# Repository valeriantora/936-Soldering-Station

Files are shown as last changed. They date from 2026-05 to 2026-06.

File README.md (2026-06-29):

# 936-Soldering-Station

The **936 Soldering Station** is an open source hardware module designed for DIY 936 style soldering station builds and controller replacements. It features a transient protected, multi stage power architecture and integrated precision calibration points for high thermal accuracy and hardware longevity.

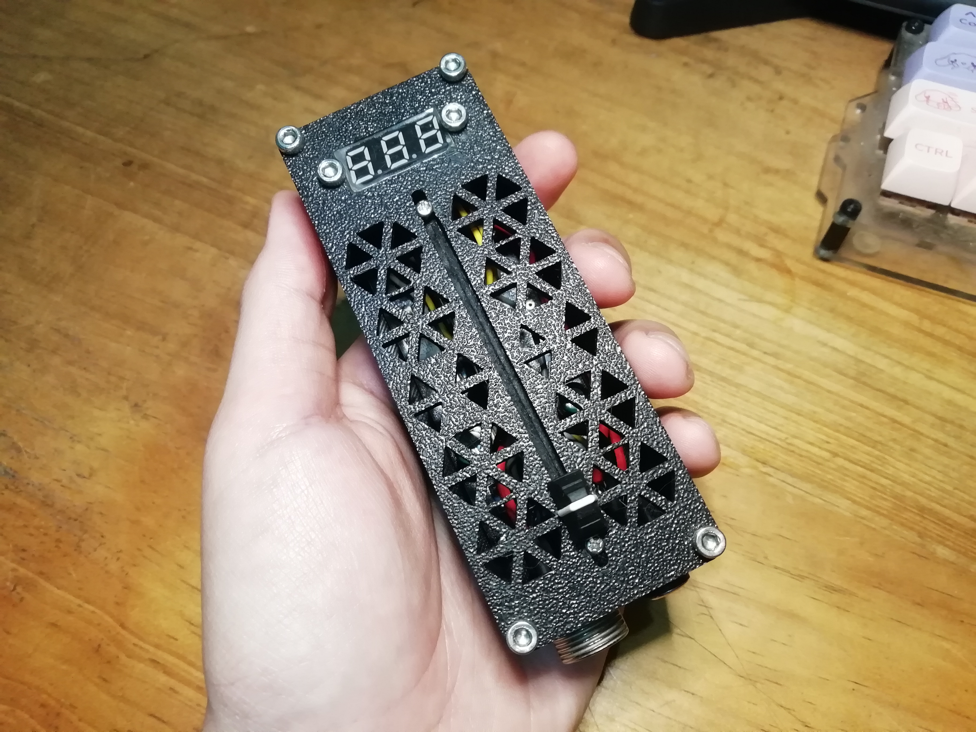
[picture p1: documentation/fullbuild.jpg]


## Key Features

* **Pure Analog Control:** Unlike many modern designs, this station uses no microcontrollers. By utilizing the widely available **[LM358](https://www.lcsc.com/datasheet/C5423.pdf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) op-amp**, the project remains easy to build, troubleshoot, and repair without the need for firmware flashing or specialized programming tools.
* **Schmitt Trigger Switching:** Utilizes to ensure the MOSFET operates strictly in a "snap-action" mode.
* **Multi-Stage Power Protection:** Implements an [LM2596S ](https://www.lcsc.com/datasheet/C347423.pdf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) buck converter to safely step down the main 24V input. This intermediate voltage then feeds the [78L12](https://www.lcsc.com/datasheet/C5337208.pdf) and [78L05](https://www.lcsc.com/datasheet/C347258.pdf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) linear regulators in parallel, preventing them from blowing out due to 24V hot-plug inductive spikes or thermal overload.
* **Temperature Monitoring:** Using a 3 wire digital voltmeter to provide real time temperature readout via calibrated analog scaling.
* **Dual Test-Point Calibration:** Equipped with dedicated onboard test points to safely measure and tune the intermediate buck regulation voltage and the amplified thermal feedback.
* **Linear Thermal Scaling:** Outbound thermocouple feedback is mapped linearly where 1V = 100°C, simplifying verification and calibration with any standard multimeter.

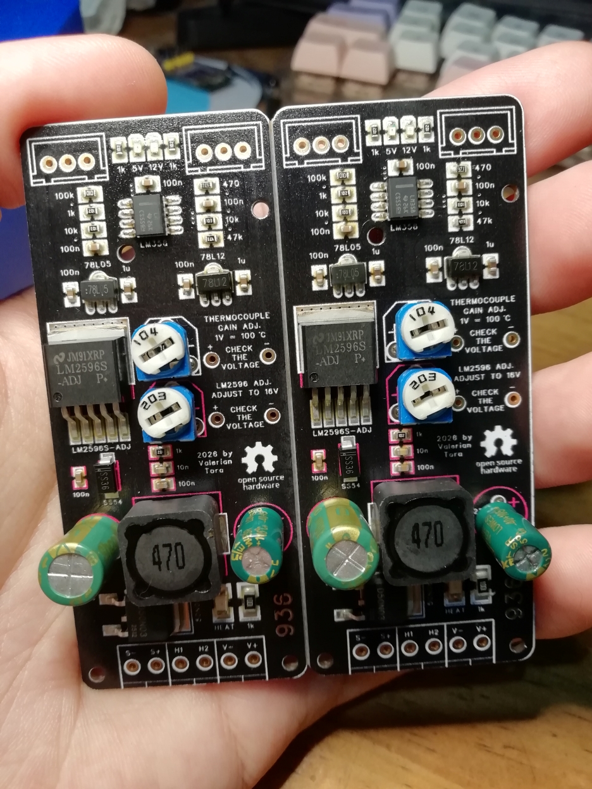
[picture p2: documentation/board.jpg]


## Technical Specifications

| Parameter | Specification |
| :--- | :--- |
| **Main Input Voltage** | 24V DC |
| **Control Architecture** | Analog Schmitt Trigger (LM358 Based) |
| **Power Supply Topology** | LM2596 Buck -> (7812 & 7805 in parallel) |
| **Analog Regulation** | 7812 (LM358 power) & 7805 (Potentiometer reference) |
| **Thermal Scaling** | 1V = 100°C at Test Point 1 (TP1) |
| **Switching Element** | TO-252 MOSFET Footprint (AOD444, 50N06, or equivalent) |

## Hardware & Calibration Layout

### 1. Power Calibration (TP2)
To protect the linear regulation stages from excessive thermal dissipation or overvoltage damage, the LM2596 output must be set precisely before reaching the 7812 and 7805 ICs.
* **Test Point:** TP2 (located directly side-by-side with the voltage calibration trimpot).
* **Procedure:** Measure voltage at TP2 against ground and adjust the potentiometer until the target pre-regulation voltage is met.

### 2. Thermal Feedback Verification (TP1)
The controller uses the LM358 op-amp (powered by the clean 12V rail) to amplify the microvolt signal from the iron's internal K-type thermocouple into a linear voltage output.
* **Test Point:** TP1 (monitors the output of the thermocouple operational amplifier).
* **Scaling Ratio:** Optimized at a 1V = 100°C ratio. For example, a reading of 3.5V directly represents a tip temperature of 350°C.

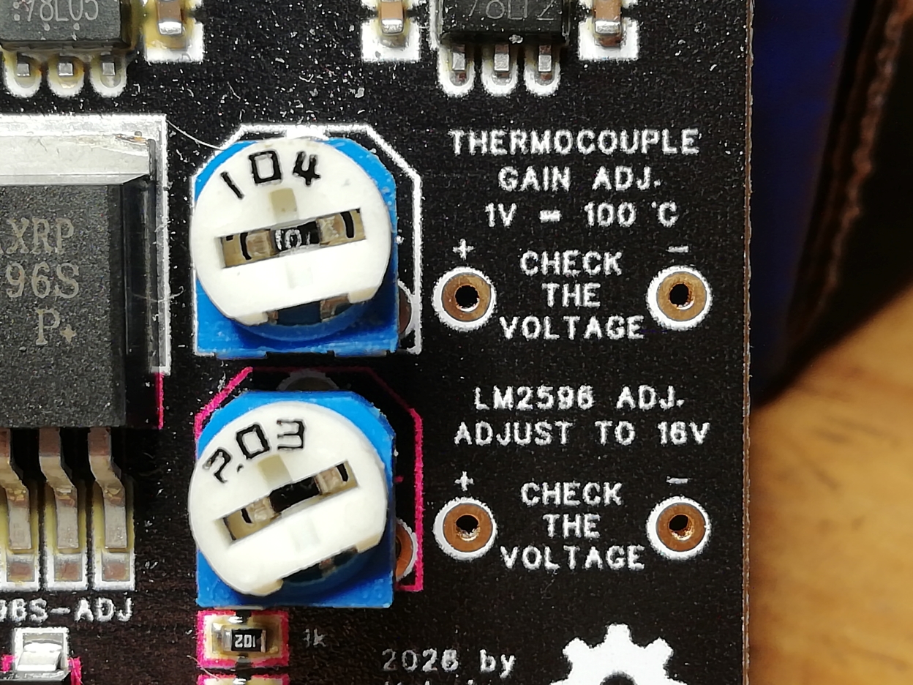
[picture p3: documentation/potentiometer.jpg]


## Digital Temperature Display (Voltmeter)

This board supports a real-time digital readout using a standard **3 wire DC Voltmeter**. Tuning the gain setting potentiometer on the PCB allows the voltmeter to accurately display the temperature.

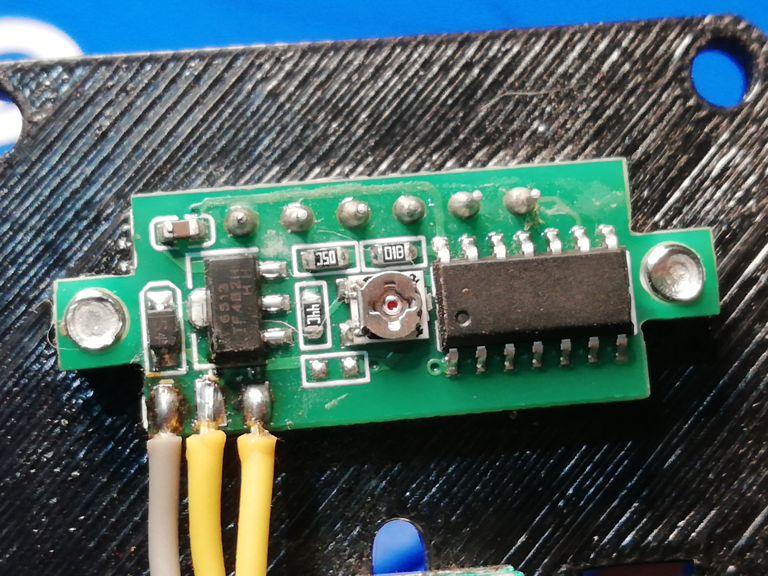
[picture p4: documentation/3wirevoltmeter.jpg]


## Identifying & Testing Your Iron Handle

This board is designed strictly for **K-Type Thermocouple** 936 handles, not the thermistor/A1321 variants. Because cheap clone handles rarely come with documentation, you can verify your handle using a multimeter and a lighter before plugging it in.

**The 5-Pin Layout Logic:**
On a standard 5-pin aviation plug, **Pin 3 (the center pin)** is always designated for Earth/Ground (ESD safe). This leaves you with two distinct pairs of pins: **Pins 1 & 2** and **Pins 4 & 5**. One pair is the 24V Heater, and the other is the Thermocouple.

**Step 1: Find the Heater Element**
1. Set your multimeter to measure Resistance (Ohms).
2. Probe the pairs. The pair that reads approximately **12Ω to 16Ω** (often around 14Ω) is your 24V heater element. 

**Step 2: The "Lighter Test" (Verify the Thermocouple)**
1. Connect your multimeter probes to the remaining pair of pins.
2. Set your multimeter to read DC millivolts (mV).
3. Take a lighter and gently apply heat to the tip of the soldering iron.
4. **The Result:** If you see the voltage slowly increase on the multimeter (even just by a few mV), you have successfully identified the K-Type thermocouple pins!

| Ohm | Thermocouple |
| --- | --- |
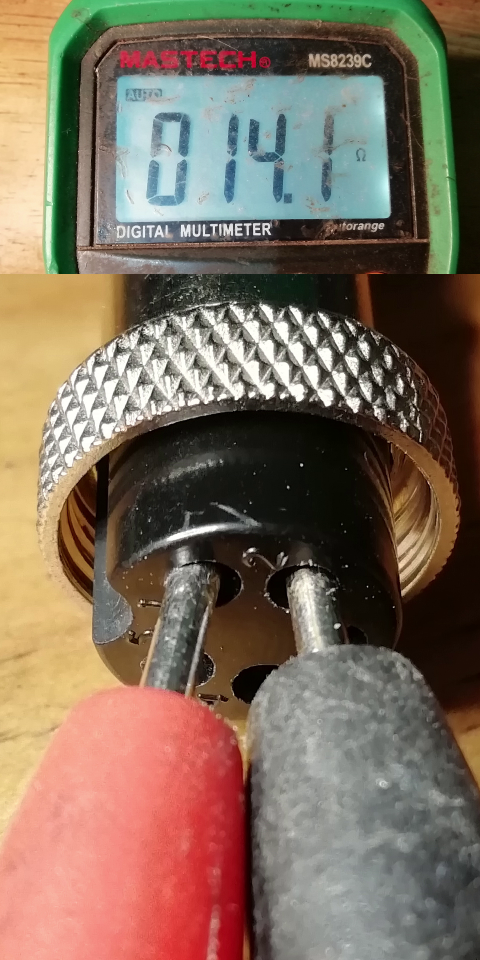
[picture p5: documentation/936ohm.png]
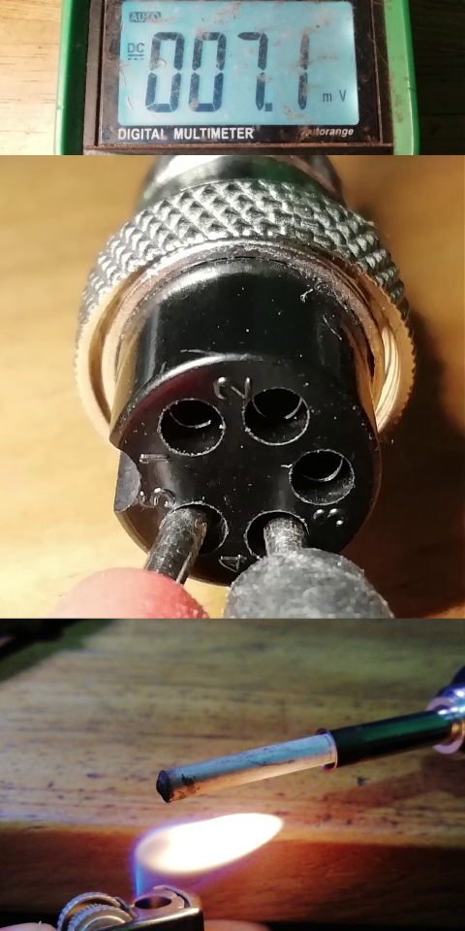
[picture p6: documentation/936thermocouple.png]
|  |  |

## Assembly & Hardware Requirements

To complete the full build beyond the main PCB assembly, you will need to source the following additional hardware parts:

* **3D-Printed Enclosure**
* **GX16 5-Pin Aviation Connector**
* **0.28" 3 Wire Digital Voltmeter**
* **DC Barrel Jack** (5.5mm × 2.1mm panel mount)
* **KCD11 Rocker Switch**
* **Slide Potentiometer** (75mm B103)
* **Some Wires**
* **Some M2 and M3 Screws** 

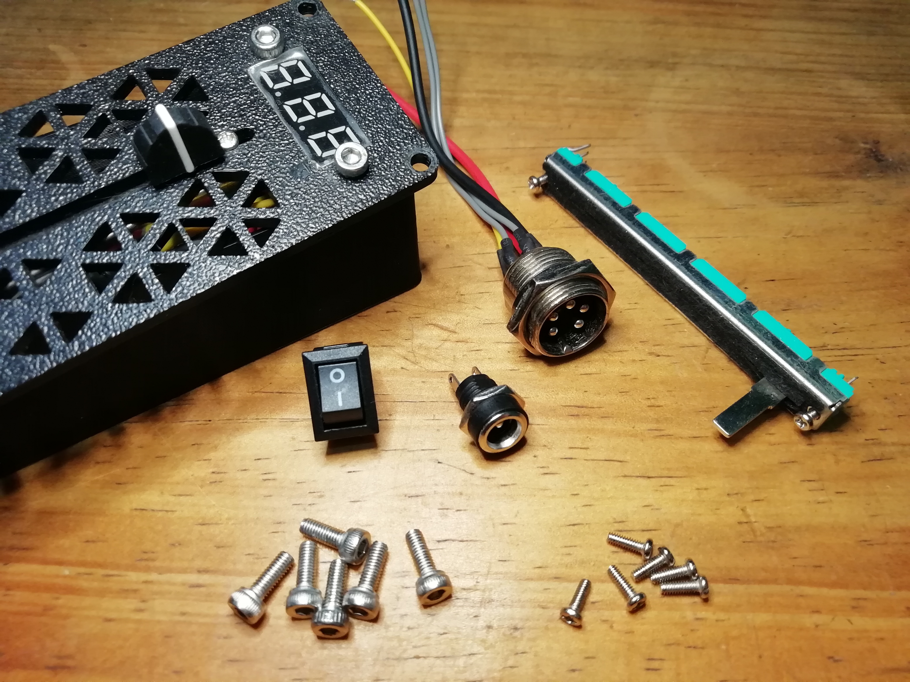
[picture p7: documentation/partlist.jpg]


The slide potentiometer features two mounting holes designed to be directly self tapped using **M2 screws**. The exact same method applies to the 0.28" digital voltmeter, which uses **M3 screws** to cut threads directly into the pcb mounting holes for a secure and stable fit inside the 3D-printed enclosure.

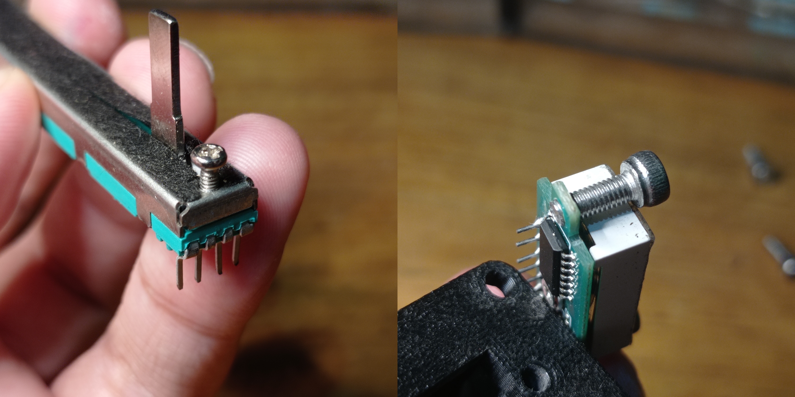
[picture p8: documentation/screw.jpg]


## Reference
- [LM358 Datasheet](https://www.lcsc.com/datasheet/C5423.pdf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)
- [LM2596S Datasheet](https://www.lcsc.com/datasheet/C347423.pdf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)
- [78L12 Datasheet](https://www.lcsc.com/datasheet/C5337208.pdf)
- [78L05 Datasheet](https://www.lcsc.com/datasheet/C347258.pdf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)

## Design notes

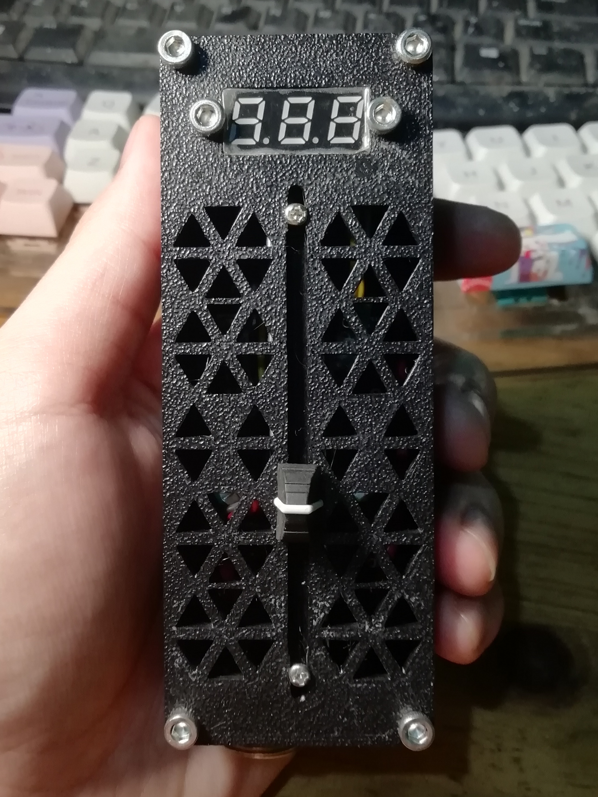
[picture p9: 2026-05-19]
documentation/front.jpg

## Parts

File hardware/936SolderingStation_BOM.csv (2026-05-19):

No. | Quantity | Comment | Designator | Footprint | Manufacturer Part | Manufacturer | Supplier | link
1 | 7 | 100n | C1,C2,C3,C5,C7,C9,C12 | 0603 | CC0603KRX7R9BB104 | YAGEO(国巨) | LCSC
2 | 2 | 1u | C4,C6 | 0603 | CL10B105KA8NNNC | SAMSUNG(三星) | LCSC
3 | 1 | 10n | C8 | 0603 | CC0603KRX7R9BB103 | YAGEO(国巨) | LCSC
4 | 1 | 220u | C10 | CAP-D8.0×F3.5 | 01EC1230 | KNSCHA(科尼盛) | LCSC
5 | 1 | 100u | C11 | CAP-D8.0×F3.5 | ERS1HM101F12OT | AISHI(艾华集团) | LCSC
6 | 1 | SS54 | D1 | DIODE-SMA(DO-214AC) | SS54 | MDD(辰达半导体) | LCSC
7 | 1 | 47uH | L1 | IND-SMD_L12.0-W12.0_CDRH127NP | PSPHAQ127-470M | PROD(谱罗德) | LCSC
8 | 1 | HEAT | LED1 | 1206 | HEAT | TUOZHAN(拓展光电) | LCSC
9 | 1 | 12V | LED2 | LED_0603 | 12V | Guiguang light(桂光光电) | LCSC
10 | 1 | 5V | LED3 | LED_0603 | 5V | HONGLITRONIC(鸿利光电) | LCSC
11 | 2 | JST XH2.54 | P4,P5 | CONN-TH_XH-3A | XH-3A | BOOMELE(博穆精密) | LCSC
12 | 1 | 50N06 | Q1 | TO-252-2 | 50N06 | KUU | LCSC
13 | 4 | 1k | R1,R7,R11,R12 | 0603 | FRC0603J102 TS | FOJAN(富捷) | LCSC
14 | 1 | 100k | R2 | RM065 | RM065-104(100K) | BOCHEN(博晨) | LCSC
15 | 1 | 100k | R3 | 0603 | FRC0603J104 TS | FOJAN(富捷) | LCSC
16 | 1 | 47k | R4 | 0603 | FRC0603J473 TS | FOJAN(富捷) | LCSC
17 | 1 | 470 | R5 | 0603 | FRC0603J471 TS | FOJAN(富捷) | LCSC
18 | 1 | 1k | R6 | 1206 | FRC1206J102 TS | FOJAN(富捷) | LCSC
19 | 1 | 20k | R8 | RM065 | RM065-203(20K) | BOCHEN(博晨) | LCSC
20 | 3 | 10k | R9,R10,R15 | 0603 | FRC0603J103 TS | FOJAN(富捷) | LCSC
21 | 1 | 0 | R13 | 1210
22 | 1 | 560k | R14 | 0603 | FRC0603J564 TS | FOJAN(富捷) | LCSC
23 | 1 | LM358 | U1 | SOP-8_150MIL | LM358 | TI(德州仪器) | LCSC
24 | 1 | 78L05 | U2 | SOT-89-3_L4.5-W2.5-P1.50-LS4.2-BR | 78L05 | OSEN(欧芯) | LCSC
25 | 1 | 78L12 | U3 | SOT-89-3_L4.5-W2.5-P1.50-LS4.2-BR | 78L12 | GR(国睿) | LCSC
26 | 1 | LM2596S-ADJ | U4 | TO-263-5_L10.2-W8.6-P1.70-LS14.4-BR | LM2596S-ADJ | GR(国睿) | LCSC

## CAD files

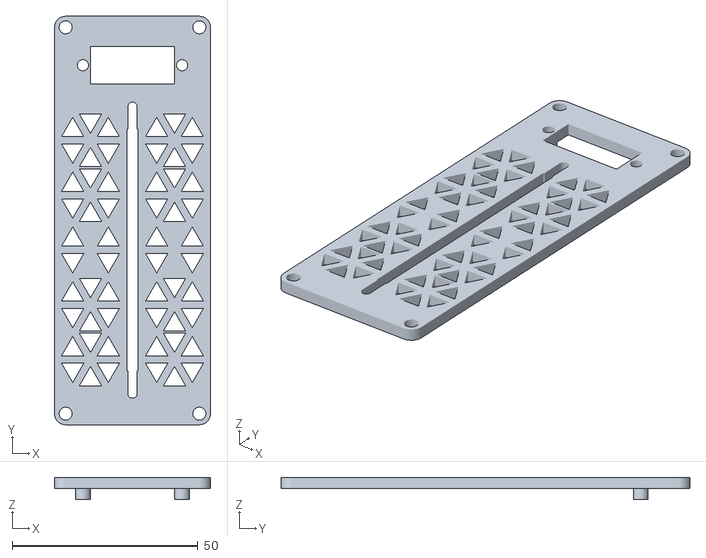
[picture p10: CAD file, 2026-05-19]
3dprint/936 Top.stl
42.0 x 110.0 x 6.00

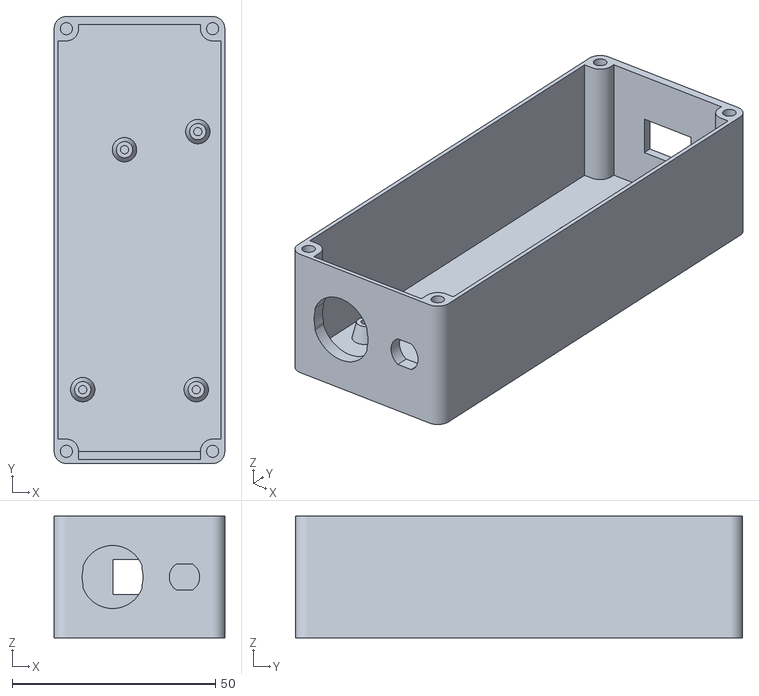
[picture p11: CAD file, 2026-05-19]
3dprint/936 Base.stl
42.0 x 110.0 x 30.0

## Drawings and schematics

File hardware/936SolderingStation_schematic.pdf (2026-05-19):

## Amplifier

Heater | Temp Pot | Temp Display

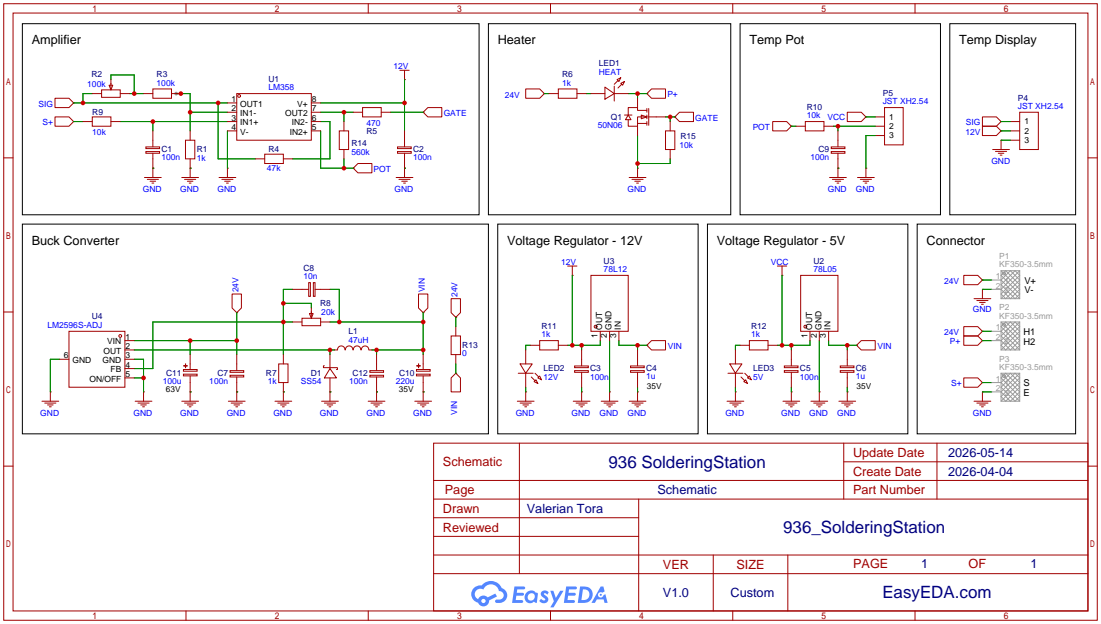
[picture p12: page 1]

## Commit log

2026-05-19 Enhance README with detailed project information
    Expanded the README to include detailed information about the 936 Soldering Station, including key features, technical specifications, calibration procedures, and reference materials.
2026-05-19 Add files to hardware
    [936SolderingStation_BOM.csv]
2026-05-22 Include board image in README
    Added an image of the board to the README.
2026-06-29 Update README for clarity and additional requirements
    Corrected formatting and improved clarity in the README. Added assembly and hardware requirements section.
